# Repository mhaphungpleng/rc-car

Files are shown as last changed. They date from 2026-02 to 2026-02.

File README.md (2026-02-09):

# RC-Car ROS2 Control System

โปรเจกต์นี้เป็นระบบควบคุมรถ RC ที่พัฒนาด้วย **ROS2**  
รองรับทั้งโหมดควบคุมแบบ **Manual (Joystick)** และ **Autonomous (PID Controller)**  
ระบบถูกออกแบบแบบ **Modular** เพื่อแยก perception, control และ hardware interface

---

## Project Structure

rc-car/
 /firmware/ # โค้ดไมโครคอนโทรลเลอร์ / ESC / Servo
 /software/ # ROS2 nodes สำหรับ manual และ autonomous control
 /models/ # สมการควบคุมและแบบจำลองทางคณิตศาสตร์
 /images/ # block diagram และ hardware setup
 /docs/ # รายงานและเอกสาร
 /launch/ # ROS2 launch files

---

## System Overview

ระบบควบคุมประกอบด้วย

- Sensor input (เช่น LiDAR)
- PID Controller สำหรับ steering และ throttle
- Manual joystick control
- ESC และ Servo สำหรับควบคุมรถ

ระบบสามารถทำงานได้ 2 โหมด

**Manual mode**

**Autonomous mode**

---

## Manual Control

Node `joy_to_manual`

Subscribe:
- `/joy`

Publish:
- `/cmd_esc_manual`
- `/cmd_s1_manual`

---

## Autonomous Control

ระบบใช้ค่า error จาก target  
คำนวณ steering และ throttle ด้วย **PID Controller**

---

## Hardware

- RC Car Platform
- ESC Motor Controller
- Steering Servo
- LiDAR Sensor
- ROS2 Computer / Embedded Controller
- Joystick Controller

Hardware diagram:

---

## Diagrams

- Block Diagram: `images/block_diagram.png`
- PID Control Diagram: `images/PID.png`
- Hardware Setup: `images/hardware_setup.png`

---

## Features

- Modular ROS2 architecture
- PID control สำหรับ steering และ throttle
- รองรับ manual override
- Smooth ESC ramp control
- สามารถต่อยอด perception และ navigation ได้

---

## Future Work

- Autonomous navigation เต็มรูปแบบ
- Obstacle avoidance
- Sensor fusion (LiDAR + Camera)
- Adaptive PID tuning

---

โปรเจกต์นี้จัดทำขึ้นเพื่อการศึกษาและพัฒนาในสาย **Robotics และ Control System**

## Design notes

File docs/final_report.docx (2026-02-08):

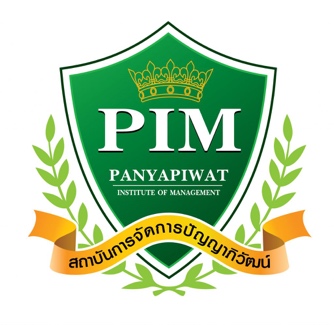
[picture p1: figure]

การทำหุ่นยนต์อัตโนมัติ

(Autonomous Robotics Project)

จัดทำโดย

นาย ภาณุภร มาศรี

นาย นฤเบศ หนูเจริญ

นาย ฟุรกอน สาแม

สาขาวิชาหุ่นยนต์และระบบอัตโนมัติ

คณะวิศวกรรมศาสตร์และเทคโนโลยี

สถาบันการจัดการปัญญาภิวัฒน์

บทคัดย่อ

หัวข้อโครงงาน: การทำหุ่นยนต์อัตโนมัติ คณะ: วิศวกรรมศาสตร์และเทคโนโลยี สาขาหุ่นยนต์และระบบอัตโนมัติ ผู้จัดทำ:นาย ภาณุภร มาศรี, นาย นฤเบศ หนูเจริญ, นาย ฟุรกอน สาแม

โครงงานนี้มีวัตถุประสงค์เพื่อศึกษาและพัฒนาหุ่นยนต์อัตโนมัติที่สามารถปฏิบัติภารกิจ [ใส่หน้าที่หลัก เช่น การเคลื่อนที่หลบหลีกสิ่งกีดขวาง / การเดินตามเส้น / การขนส่งวัสดุ] โดยเน้นการบูรณาการองค์ความรู้ด้านวิศวกรรมหุ่นยนต์ ทั้งในส่วนของการออกแบบโครงสร้างทางกล (Mechanical Design) การออกแบบวงจรระบบควบคุม (Electronic Circuit) และการพัฒนาซอฟต์แวร์ควบคุม (Firmware Development)

ในการพัฒนาหุ่นยนต์ครั้งนี้ ได้เลือกใช้ [ระบุบอร์ดควบคุม เช่น ไมโครคอนโทรลเลอร์ ESP32 / Arduino] เป็นหน่วยประมวลผลหลัก ทำงานร่วมกับเซนเซอร์ [ระบุชื่อเซนเซอร์ เช่น อัลตราโซนิก / อินฟราเรด] เพื่อรับข้อมูลสภาพแวดล้อม และขับเคลื่อนด้วย [เช่น Butlet Motor ผ่านโมดูลขับมอเตอร์ การเขียนโปรแกรมควบคุมใช้อัลกอริทึม PID Control เพื่อให้หุ่นยนต์สามารถตัดสินใจและตอบสนองต่อเงื่อนไขต่างๆ ได้อย่างแม่นยำ

จากการทดสอบประสิทธิภาพการทำงานของหุ่นยนต์ในสภาพแวดล้อมจำลอง พบว่าหุ่นยนต์สามารถ [ระบุผลการทดลอง เช่น เคลื่อนที่ไปยังจุดหมายได้อย่างถูกต้อง / ตรวจจับสิ่งของได้ในระยะ 1.5 เมตรโดยมีอัตราความสำเร็จในการปฏิบัติงานเฉลี่ยร้อยละ 90% อย่างไรก็ตาม ยังมีข้อจำกัดในเรื่อง ที่ตัวหุ่นยนต์ไม่สามารถล็อก target ได้ตามที่ต้องการสามารถมี่สิ่งของอื่นมารบกวนการตรวจจับของเซนเซอร์ได้ซึ่งสามารถนำไปพัฒนาต่อยอดในเชิงอุตสาหกรรมหรือการใช้งานที่ซับซ้อนขึ้นในอนาคต

สารบัญ (Table of Contents)

บทคัดย่อ ......................................................................................................................... ก

สารบัญเนื้อหา.................................................................................................................... ข

บทที่ 1 บทนำ....................................................................................................................1

- 1.1 ที่มาและความสำคัญของโครงงาน ................................................................................................................ 1
- 1.2 วัตถุประสงค์ของโครงงาน ........................................................................................................................... 2
- 1.3 ขอบเขตการดำเนินงาน ................................................................................................................................. 2
- 1.4 ผู้ใช้งานของโครงงาน ................................................................................................................................... 3
- 1.5 ประโยชน์ที่คาดว่าจะได้รับ ........................................................................................................................... 3

บทที่ 2 ฐานข้อมูลและการประยุกต์ใช้ระบบควบคุม ......................................................................... 4

- 2.1 ฐานข้อมูลการทดสอบรถอัตโนมัติ ................................................................................................................ 4
- 2.2 ฐานข้อมูลเซนเซอร์ ....................................................................................................................................... 4
- 2.3 การประยุกต์ใช้ Machine Learning และระบบควบคุม .................................................................. 5
  - 2.3.1 การควบคุมความเร็วด้วยสมการ PID ......................................................... 5
  - 2.3.2 การควบคุมทิศทางด้วย Gyroscope และเซอร์โวมอเตอร์ ................................................. 5
- 2.4 ฐานข้อมูลในการตัดสินใจเลือกอุปกรณ์ (เอกสารอ้างอิงชุดอุปกรณ์) ............................................................ 6

บทที่ 3 วิธีดำเนินงาน ....................................................................................................... 7

- 3.1 เครื่องมือที่ใช้ (Hardware) ............................................................................. 7
- 3.2 ซอฟต์แวร์ที่ใช้ในการพัฒนา (Software)................................................................ 8
  - 3.2.1 ระบบปฏิบัติการ Ubuntu และ ROS 2 .................................................. 8
  - 3.2.2 Arduino IDE และการออกแบบทางวิศวกรรม (SolidWorks / Fusion 360) .. .......................................................................................................... 9
- 3.3 ขั้นตอนการดำเนินงาน ................................................................................................................................. 10
  - 3.3.1 การออกแบบและประกอบโครงสร้างรถต้นแบบ .................................................................... 10
  - 3.3.2 การพัฒนาโปรแกรมควบคุมและปัญหาการรับส่งข้อมูล ......................................................... 11
  - 3.3.3 การจัดการสัญญาณรบกวนด้วย Alpha Filter .......................................... 12
  - 3.3.4 การประยุกต์ใช้ Lidar และการจัดการ Node ใน ROS 2 ............................ 13
  - 3.3.5 แนวคิดการออกแบบระบบแซงอัตโนมัติ ................................................................................. 14

บทที่ 4 การพัฒนาและการทำงานของระบบซอฟต์แวร์ ................................................................... 15

- 4.1 ภาพรวมสถาปัตยกรรมซอฟต์แวร์ ................................................................................................................ 15
- 4.2 ระบบควบคุมพวงมาลัยอัตโนมัติจาก LiDAR (PD Controller) ............................... 16
- 4.3 ระบบควบคุมรถด้วยคีย์บอร์ด (Manual Control) ................................................. 17
- 4.4 ระบบกราฟิกยูสเซอร์อินเทอร์เฟซ (GUI) ............................................................... 18
- 4.5 การจัดการโค้ดและโครงสร้างโปรแกรม ...................................................................................................... 19
- 4.6 สรุปการทำงานของระบบ ..............................................................................................................................19

บทที่ 5 สรุปผลการดำเนินงานและข้อเสนอแนะ ........................................................................... 20

- 5.1 สรุปผลการดำเนินงาน ................................................................................................................................... 20
- 5.2 ปัญหาและอุปสรรคที่พบ ............................................................................................................................... 21
- 5.3 ข้อเสนอแนะและแนวทางการพัฒนาต่อยอด ................................................................................................. 21

บทที่ 1

บทนำ

### ที่มาและความสำคัญของโครงงาน

กลุ่มผู้จัดทำได้เลือกพัฒนารถต้นแบบขึ้นมาใหม่ทั้งคัน ตั้งแต่การออกแบบโครงสร้างและบอดี้ของรถ ไปจนถึงการพัฒนาระบบการทำงานต่าง ๆ ของตัวรถ เนื่องจากเล็งเห็นว่าการดำเนินโครงงานในลักษณะนี้สามารถช่วยพัฒนาความรู้และทักษะของผู้จัดทำได้ในหลากหลายด้าน การสร้างรถหนึ่งคันจำเป็นต้องอาศัยกระบวนการทำงานหลายส่วน ไม่ว่าจะเป็นการออกแบบตัวรถ ซึ่งไม่ได้เป็นเพียงการออกแบบในเชิงรูปลักษณ์เท่านั้น แต่ยังต้องมีการคำนวณและวิเคราะห์ในแต่ละจุด เพื่อให้รถสามารถเคลื่อนที่ได้อย่างมีประสิทธิภาพ มีความเสถียร และสามารถทำความเร็วได้ตามที่ต้องการ

นอกจากนี้ โครงงานยังประกอบด้วยการพัฒนาระบบควบคุม การเขียนโปรแกรม รวมถึงการออกแบบและต่อวงจรไฟฟ้าให้สามารถทำงานร่วมกันได้อย่างเหมาะสม กระบวนการเหล่านี้ช่วยเสริมสร้างความเข้าใจด้านวิศวกรรม การแก้ไขปัญหาเชิงระบบ และการทำงานเป็นทีม ส่งผลให้ผู้จัดทำสามารถพัฒนาศักยภาพและทักษะทางเทคนิคได้อย่างรอบด้าน

### วัตถุประสงค์ของโครงงาน

1. เพื่อศึกษาการประยุกต์ใช้เทคโนโลยีเซนเซอร์และระบบควบคุมอัตโนมัติในงานยานยนต์อัจฉริยะ
2. เพื่อออกแบบและพัฒนารถต้นแบบที่สามารถเคลื่อนที่ได้ด้วยตนเอง
3. เพื่อพัฒนาระบบควบคุมการเคลื่อนที่ของรถให้สามารถติดตามรถคันข้างหน้าโดยอัตโนมัติ
4. เพื่อออกแบบระบบตรวจจับสภาพแวดล้อมรอบตัวรถ เช่น ระยะห่างและตำแหน่งของรถคันอื่น
5. เพื่อพัฒนาระบบตัดสินใจในการแซงรถคันข้างหน้าอย่างอัตโนมัติภายใต้เงื่อนไขที่กำหนด

### ขอบเขตการดำเนินงาน

ในขั้นตอนแรก กลุ่มผู้จัดทำได้ดำเนินการออกแบบโครงสร้างและบอดี้ของรถ โดยใช้โปรแกรม Fusion 360 เพื่อออกแบบและจำลองการทำงานของตัวรถในลักษณะสามมิติ เพื่อประเมินความเหมาะสมของโครงสร้างและความเป็นไปได้ในการใช้งานจริง

ควบคู่ไปกับการออกแบบเชิงกล กลุ่มผู้จัดทำได้พัฒนาชุดคำสั่งพื้นฐานสำหรับควบคุมการทำงานของระบบ โดยอาศัยหลักการเขียนโปรแกรมพื้นฐาน เช่น การกำหนดตัวแปร การใช้คำสั่งเงื่อนไข การวนซ้ำ และการแบ่งโปรแกรมออกเป็นฟังก์ชัน ซึ่งถือเป็นพื้นฐานสำคัญในการพัฒนาระบบควบคุมรถอัตโนมัติให้สามารถทำงานได้อย่างถูกต้องและมีประสิทธิภาพ

### ผู้ใช้งานของโครงงาน

ผู้ใช้งานของโครงงานนี้ ได้แก่ ผู้จัดทำและผู้ที่เกี่ยวข้องกับการทดสอบระบบ โดยมีวัตถุประสงค์เพื่อใช้ในการศึกษา ทดลอง และพัฒนาทางเทคโนโลยี

### ประโยชน์ที่คาดว่าจะได้รับ

ชิ้นงานของกลุ่มผู้จัดทำมีศักยภาพในการเป็นแนวทางหรือแรงบันดาลใจให้แก่ผู้ที่สนใจในการพัฒนาโครงงานด้านยานยนต์อัตโนมัติ ซึ่งสามารถนำไปต่อยอดในการสร้างหรือพัฒนาชิ้นงานในลักษณะเดียวกันได้

สำหรับกลุ่มผู้จัดทำ โครงงานนี้ช่วยเสริมสร้างความรู้ ความสามารถ และทักษะในหลายด้าน ไม่ว่าจะเป็นด้านการวางแผน การออกแบบ การพัฒนาระบบ การแก้ไขปัญหา และการทำงานเป็นทีม อีกทั้งยังสามารถนำองค์ความรู้และประสบการณ์ที่ได้รับไปประยุกต์ใช้กับงานหรือโครงการอื่น ๆ ในอนาคตได้

บทที่ 2

### ฐานข้อมูลการทดสอบรถอัตโนมัติ

ใช้สำหรับจัดเก็บข้อมูลที่ได้จากการทดสอบระบบรถอัตโนมัติในแต่ละครั้ง เพื่อใช้ในการวิเคราะห์ประสิทธิภาพของระบบ

ข้อมูลที่จัดเก็บประกอบด้วย

- วันที่และเวลาที่ทำการทดสอบ
- ความเร็วของรถ
- ระยะห่างจากรถคันหน้า
- สถานะการแซง (แซง / ไม่แซง)
- ผลการทำงานของระบบ (สำเร็จ / ล้มเหลว)

ข้อมูลดังกล่าวถูกนำมาใช้ในการเปรียบเทียบผลการทดสอบในแต่ละครั้ง เพื่อประเมินประสิทธิภาพและความเสถียรของระบบ

### ฐานข้อมูลเซนเซอร์

ใช้สำหรับจัดเก็บค่าที่อ่านได้จากเซนเซอร์ต่าง ๆ แบบต่อเนื่อง เพื่อใช้ในการประมวลผลและวิเคราะห์การทำงานของระบบ

ข้อมูลที่จัดเก็บประกอบด้วย

- ค่าที่อ่านจาก Ultrasonic / Camera
- ระยะห่าง (เซนติเมตร)
- เวลาที่อ่านค่า

### การประยุกต์ใช้ Machine Learning และระบบควบคุม

ในการควบคุมให้หุ่นยนต์สามารถตัดสินใจได้ว่าจะต้องชะลอความเร็ว เร่งความเร็ว แซง หรือเลี้ยว กลุ่มผู้จัดทำได้ออกแบบระบบควบคุมโดยอาศัยข้อมูลจากเซนเซอร์ต่าง ๆ ที่ติดตั้งบนหุ่นยนต์

สำหรับการควบคุมความเร็ว หุ่นยนต์จะใช้เซนเซอร์วัดระยะทางเพื่อตรวจจับระยะห่างจากวัตถุหรือรถคันหน้า ข้อมูลที่ได้จะถูกนำไปประมวลผลด้วยสมการควบคุมแบบ PID (Proportional–Integral–Derivative) เพื่อคำนวณค่าที่เหมาะสมในการเร่งหรือชะลอความเร็วของมอเตอร์ ทำให้หุ่นยนต์สามารถปรับความเร็วได้อย่างเหมาะสมและมีความเสถียร

ในส่วนของการควบคุมทิศทางการเคลื่อนที่ หุ่นยนต์ใช้เซนเซอร์ไจโรสโคป (Gyroscope) ในการตรวจจับมุมการเอียงหรือมุมการหมุนของตัวรถ เมื่อระบบตรวจพบว่ารถเบี่ยงออกจากแนวที่กำหนด ข้อมูลดังกล่าวจะถูกนำไปสั่งงานเซอร์โวมอเตอร์ให้ปรับมุมในทิศทางตรงกันข้าม

ตัวอย่างเช่น หากตรวจพบการเอียงจำนวน 3 องศา ระบบจะสั่งให้เซอร์โวมอเตอร์ปรับมุม 3 องศาในทิศทางตรงกันข้าม เพื่อแก้ไขทิศทางให้รถกลับมาเคลื่อนที่ในแนวที่ถูกต้อง ส่งผลให้การเคลื่อนที่มีความแม่นยำและปลอดภัยมากยิ่งขึ้น

ฐานข้อมูลในการตัดสินใจเลือกอุปกรณ์

Espressif Systems. (n.d.). *ESP32 – Wikipedia*. Retrieved January 2026, from https://en.wikipedia.org/wiki/ESP32

MG996R Servo Motor Specifications, ETT Co., Ltd. (n.d.). Retrieved January 2026, from https://www.etteam.com

Arduino4Pro. (n.d.). *LiPo battery category*. Retrieved January 2026, from https://www.arduino4pro.com/category/152/power-supply-regulator/lipo-litium-battery-charger

Hobbywing. (n.d.). *Skywalker ESC specifications*. Retrieved January 2026, from https://www.hobbywing.com/en/uploads/file/95b6d53e5e0c47b04f0054db6e894e31.pdf

Web Electronics Parts Category. (n.d.). *DC-DC step down regulators*. Retrieved January 2026, from https://www.as99shop.com/category/switching-powersupply/step-down-regulator

YDLIDAR X3 Pro Lidar. (n.d.). Retrieved January 2026, from https://www.arduitronics.com/product/5678/ydlidar-x3-pro-lidar-360-degree-laser-range-scanner-8m-support-ros1-ros2

Raspberry Pi Foundation. (n.d.). *Raspberry Pi 5 documentation*. Retrieved January 2026, from https://www.raspberrypi.com/products/raspberry-pi-5/

บทที่ 3

## วิธีดำเนินงาน

### เครื่องมือที่ใช้

#### Hardware

- โช้คไฮดรอลิกโลหะ ใช้เพื่อช่วยเพิ่มเสถียรภาพของรถขณะเคลื่อนที่และรองรับการทำความเร็ว
- ESP32 Mini ทำหน้าที่รับข้อมูลจากเซนเซอร์ต่าง ๆ ประมวลผล และควบคุมการทำงานของมอเตอร์ตามโปรแกรมที่เขียนไว้
- Servo Motor ทำหน้าที่ควบคุมการเลี้ยวของรถ เนื่องจากสามารถปรับมุมได้อย่างแม่นยำ
- เกลียวทองเหลือง ใช้สำหรับยึดน็อตและชิ้นส่วนต่าง ๆ
- เพลาสแตนเลส ทำหน้าที่ส่งแรงหมุนจากมอเตอร์ไปยังล้อ
- ตลับลูกปืน
- ล้อรถ
- แบตเตอรี่ LiPo 2S 7.4V 2200 mAh ทำหน้าที่เป็นแหล่งจ่ายพลังงานหลักให้กับระบบทั้งหมดของรถต้นแบบ
- สกรู
- บัลเลตมอเตอร์ ทำหน้าที่เป็นแหล่งกำลังขับเคลื่อนหลักของรถ
- Skywalker ไดรฟ์มอเตอร์ (ESC) ใช้ควบคุมการหมุนและความเร็วของมอเตอร์ รวมถึงรองรับการเบรก
- ToF Sensor ใช้เป็นเซนเซอร์วัดระยะทาง
- DC-DC Converter 5V 5A ใช้ลดแรงดันไฟจากแบตเตอรี่ให้อยู่ในระดับที่อุปกรณ์สามารถใช้งานได้
- Connector ใช้สำหรับเชื่อมต่ออุปกรณ์ เพื่อความสะดวกในการถอดประกอบ

Software:

### Ubuntu (Operating System) ใช้เป็นระบบปฏิบัติการหลักสำหรับการพัฒนาและควบคุมระบบหุ่นยนต์ รวมถึงการติดตั้ง ROS2 และการประมวลผลข้อมูลจากเซนเซอร์ Ubuntu เป็นระบบปฏิบัติการแบบโอเพนซอร์สที่ใช้เป็นแพลตฟอร์มหลักในการพัฒนาและควบคุมระบบของหุ่นยนต์ โดยรองรับการทำงานของ ROS2 และการประมวลผลข้อมูลจากเซนเซอร์ต่าง ๆ

### ROS 2 (Robot Operating System 2)

- จัดการการสื่อสารระหว่าง NODE
- ประมวลผลข้อมูลจาก LiDAR
- ควบคุมการตัดสินใจ เช่น การตามรถและการแซง

### ROS 2 เป็นเฟรมเวิร์กสำหรับพัฒนาระบบหุ่นยนต์ ทำหน้าที่จัดการการสื่อสารและประมวลผลข้อมูลระหว่างอุปกรณ์และซอฟต์แวร์ต่าง ๆ ภายในระบบ ทำให้สามารถควบคุมการเคลื่อนที่และการตัดสินใจของหุ่นยนต์ได้อย่างมีประสิทธิภาพ

### Arduino IDE ใช้สำหรับเขียนและอัปโหลดโปรแกรมไปยัง ESP32 เพื่อควบคุมอุปกรณ์ฮาร์ดแวร์ เช่น มอเตอร์ เซอร์โว และ ESC Arduino IDE ใช้สำหรับพัฒนาและอัปโหลดโปรแกรมควบคุมไปยังไมโครคอนโทรลเลอร์ ESP32 เพื่อควบคุมการทำงานของอุปกรณ์ต่าง ๆ ภายในระบบ เช่น มอเตอร์และเซอร์โวมอเตอร์

### SolidWorks

ใช้สำหรับออกแบบชิ้นส่วนทางกลและโครงสร้างของรถ เช่น บอดี้รถ ฐานยึดอุปกรณ์ และโครงสร้างตัวถัง SolidWorks เป็นโปรแกรมออกแบบทางวิศวกรรมสามมิติ ใช้สำหรับออกแบบโครงสร้างและชิ้นส่วนทางกลของรถต้นแบบ เพื่อให้สามารถวางอุปกรณ์และประกอบระบบได้อย่างเหมาะสม

### Fusion 360 (Fusion3D) ใช้ในการออกแบบชิ้นส่วน 3 มิติและปรับแก้โมเดลก่อนนำไปผลิตจริง เช่น การพิมพ์ 3 มิติ Fusion 360 ใช้สำหรับออกแบบและปรับแก้ชิ้นส่วนสามมิติ รวมถึงเตรียมโมเดลสำหรับการผลิต เช่น การพิมพ์สามมิติ เพื่อให้ชิ้นส่วนสามารถใช้งานได้จริงกับรถต้นแบบ

## ขั้นตอนการดำเนินงาน

ในขั้นเริ่มต้น ภายหลังจากได้รับโจทย์จากอาจารย์ผู้สอน กลุ่มผู้จัดทำได้พิจารณาถึงลักษณะของรถต้นแบบที่ต้องนำมาใช้งานร่วมกัน โดยเนื่องจากรถของอาจารย์มีความเร็วค่อนข้างสูง และโครงงานที่พัฒนาขึ้นเป็นรถระบบอัตโนมัติที่ต้องสามารถติดตามรถคันหน้าได้อย่างต่อเนื่อง หากรถมีความเร็วไม่เพียงพออาจทำให้ระบบติดตามล้มเหลวหรือหลุดจากการควบคุม กลุ่มผู้จัดทำจึงมีแนวคิดในการเลือกใช้มอเตอร์ที่สามารถให้ความเร็วและกำลังขับสูง

อย่างไรก็ตาม จากการศึกษาและทดลองพบว่ามอเตอร์ที่มีกำลังขับสูงส่วนใหญ่มักมีข้อจำกัดด้านการเบรก เนื่องจากแรงขับที่มาก ส่งผลให้ไม่สามารถควบคุมการหยุดหรือชะลอความเร็วได้อย่างมีประสิทธิภาพ ซึ่งถือเป็นปัญหาแรกที่พบ นอกจากนี้ ระหว่างกระบวนการประกอบรถต้นแบบยังพบปัญหาย่อยอื่น ๆ เช่น อุปกรณ์บางชนิดไม่สามารถใช้งานได้ตามที่คาดหวัง และโครงสร้างบอดี้ของรถที่ประกอบแล้วเกิดความไม่พอดีกันในบางตำแหน่ง

ต่อมา กลุ่มผู้จัดทำได้เริ่มดำเนินการออกแบบตัวรถ โดยเริ่มจากการออกแบบบอดี้ของรถให้สามารถเคลื่อนที่ได้ด้วยความเร็วสูง พร้อมทั้งยังต้องรองรับการเลี้ยวได้อย่างมีประสิทธิภาพ ควบคู่ไปกับการออกแบบวงจรไฟฟ้าที่ใช้ในระบบของรถต้นแบบ เมื่อได้รูปแบบการออกแบบที่เหมาะสมแล้ว จึงดำเนินการประกอบตัวรถและจัดวางตำแหน่งอุปกรณ์ต่าง ๆ เพื่อประเมินลักษณะการทำงานโดยรวมของรถในเบื้องต้น

หลังจากนั้น กลุ่มผู้จัดทำได้เริ่มพัฒนาโปรแกรมควบคุมการทำงานของรถ โดยเริ่มจากการเขียนโค้ดพื้นฐาน (Basic Code) เพื่อทดสอบการรับและส่งค่าของอุปกรณ์ไฟฟ้าต่าง ๆ ผ่านไมโครคอนโทรลเลอร์ ESP32 C3 จากการทดลองอัปโหลด Micro-ROS พบว่าไม่สามารถรันโปรแกรมได้ เนื่องจากข้อจำกัดด้านสมรรถนะการประมวลผลของตัวไมโครคอนโทรลเลอร์

ต่อมาได้ทดลองใช้งานเซนเซอร์ Gyroscope รุ่น 5883L แต่ไม่สามารถดึงค่ามุม Yaw ออกมาใช้งานได้ จากนั้นจึงเริ่มพัฒนาและเขียนโปรแกรม Micro-ROS อย่างจริงจัง ซึ่งในขั้นตอนนี้พบปัญหาตั้งแต่ระยะเริ่มต้น กล่าวคือ หลังจากอัปโหลดโค้ดทั้งหมดแล้ว ระบบสามารถรับและส่งข้อมูลได้เพียงประมาณ 1 Hz ทำให้การตอบสนองของระบบล่าช้าเกินไป

กลุ่มผู้จัดทำจึงทำการตรวจสอบสาเหตุและพบว่าอุปกรณ์ที่ใช้งานร่วมกับ Raspberry Pi จำเป็นต้องใช้บอร์ดเวอร์ชัน 2.0.2 หลังจากติดตั้งเวอร์ชันดังกล่าวแล้ว พบปัญหาใหม่คือ Arduino IDE ไม่สามารถคอมไพล์โปรแกรมได้ เนื่องจากไม่สามารถค้นหาไฟล์ Python ที่เกี่ยวข้องได้ กลุ่มผู้จัดทำจึงแก้ไขปัญหาโดยการรันโปรแกรมผ่านไฟล์ environment ของ Python จนสามารถคอมไพล์ได้สำเร็จ

เมื่อทำการทดสอบระบบอีกครั้ง พบว่าความเร็วในการรับส่งข้อมูลเพิ่มขึ้น แต่ค่าที่ได้จากเซนเซอร์ยังมีความไม่เสถียร กลุ่มผู้จัดทำจึงปรับหน่วงค่าของเซนเซอร์เพื่อให้ข้อมูลมีความเหมาะสมมากขึ้น อย่างไรก็ตาม เมื่อเริ่มนำค่าที่ได้ไปควบคุมเซอร์โวมอเตอร์ พบว่าเซอร์โวเกิดอาการส่ายอย่างรุนแรง จึงแก้ไขปัญหาโดยการเพิ่ม Alpha Filter เพื่อทำให้ค่าที่ได้มีความนิ่งมากขึ้น แม้ว่าจะทำให้การตอบสนองช้าลงบ้าง แต่ช่วยเพิ่มความเสถียรให้กับระบบโดยรวม

ในขั้นตอนถัดมา กลุ่มผู้จัดทำได้ทดลองใช้งานเซนเซอร์ที่เคยใช้งานก่อนหน้านี้ แต่พบว่าไม่สามารถตรวจจับวัตถุได้ในระยะที่ต้องการ จึงตัดสินใจเปลี่ยนมาใช้เซนเซอร์ Lidar จากการทดลองใช้งาน พบปัญหาในขั้นแรกคือไม่สามารถสั่งให้ Lidar ทำการสแกนผ่านระบบ ROS2 ได้ เนื่องจากโค้ดที่ผู้ผลิตให้มาไม่สามารถรันได้ กลุ่มผู้จัดทำจึงทำการแก้ไขโค้ดต้นฉบับของ Lidar จนสามารถสั่งงานให้ทำการสแกนผ่าน ROS2 ได้สำเร็จ

เมื่อทดสอบการทำงานของ Lidar ร่วมกับอุปกรณ์อื่น ๆ เช่น Gyroscope พบปัญหาเพิ่มเติม กล่าวคือ เมื่อมีการสั่งงานอุปกรณ์หลายชนิดพร้อมกัน ข้อมูลที่ส่งมาจาก Lidar และ Gyroscope ในเวลาใกล้เคียงกัน ส่งผลให้เซอร์โวมอเตอร์เกิดอาการส่ายอย่างรุนแรงอีกครั้ง กลุ่มผู้จัดทำจึงแก้ไขปัญหาโดยการออกแบบและเขียน Node ใหม่ในระบบ ROS2 ให้รวมการประมวลผลข้อมูลจากเซนเซอร์หลายตัวไว้ใน Node เดียวกัน เพื่อให้การส่งข้อมูลเป็นไปในลักษณะรวมศูนย์ ส่งผลให้ค่าที่ใช้ควบคุมมีความเสถียรมากขึ้นและลดอาการส่ายของเซอร์โวมอเตอร์ได้อย่างมีประสิทธิภาพ

ภายหลังจากที่กลุ่มผู้จัดทำสามารถแก้ไขปัญหาในขั้นตอนดังกล่าวและทำให้ระบบควบคุมการเคลื่อนที่ของรถมีความเสถียรแล้ว ขั้นตอนถัดมาคือการพัฒนาระบบให้รถสามารถทำการแซงได้โดยอัตโนมัติ เมื่อมีสิ่งกีดขวางหรือรถคันอื่นอยู่ด้านหน้ารถต้นแบบ

กลุ่มผู้จัดทำได้ออกแบบแนวคิดการแซงอัตโนมัติโดยอาศัยการกำหนดเงื่อนไขภายในโปรแกรมควบคุม เมื่อระบบตรวจจับได้ว่ารถเข้าใกล้วัตถุด้านหน้าในระยะที่กำหนดไว้ในโค้ด รถจะทำการเปลี่ยนโหมดการทำงานจากโหมดติดตามเป็นโหมดแซงอัตโนมัติ และดำเนินการตามค่าที่ได้ตั้งค่าไว้ล่วงหน้า

ตัวอย่างเช่น เมื่อเซนเซอร์ตรวจพบสิ่งกีดขวางอยู่ในระยะที่กำหนด ระบบจะสั่งให้รถเลี้ยวไปทางด้านขวา พร้อมทั้งเร่งความเร็วเพื่อทำการแซง โดยจะคงการเร่งความเร็วไว้เป็นระยะเวลาประมาณ 2 วินาที หลังจากนั้นระบบจะสั่งให้รถกลับเข้าสู่ทิศทางเดิม และปรับการเคลื่อนที่ให้วิ่งตรงไปข้างหน้าอย่างต่อเนื่อง โดยไม่มีการติดตามรถคันหน้าอีกต่อไปในช่วงเวลาดังกล่าว

ในขั้นตอนสุดท้าย กลุ่มผู้จัดทำได้พัฒนาและเพิ่มระบบส่วนติดต่อผู้ใช้งาน (Graphical User Interface: GUI) เพื่ออำนวยความสะดวกในการควบคุมรถต้นแบบผ่านหน้าจอ ผู้ใช้งานสามารถปรับค่าพารามิเตอร์ต่าง ๆ ของระบบได้ตามต้องการ รวมถึงสามารถเลือกโหมดการทำงานของรถได้ทั้งในโหมดควบคุมด้วยตนเอง (Manual Mode) และโหมดอัตโนมัติ (Auto Mode)

จากการดำเนินงานทั้งหมด ส่งผลให้รถต้นแบบสามารถทำงานได้ตามวัตถุประสงค์ที่กำหนดไว้ และยังสามารถนำระบบที่พัฒนาขึ้นไปปรับปรุง แก้ไข หรือพัฒนาต่อยอดเพิ่มเติมในอนาคตได้ตามความเหมาะสม

บทที่ 4

การพัฒนาและการทำงานของระบบซอฟต์แวร์

## 4.1 ภาพรวมสถาปัตยกรรมซอฟต์แวร์

ระบบซอฟต์แวร์ของโครงงานนี้พัฒนาบนระบบปฏิบัติการ Ubuntu และใช้ ROS 2 (Robot Operating System 2) เป็นแกนกลางในการสื่อสารระหว่างโหนด (Node) ต่าง ๆ ภายในระบบ โดยมีการแบ่งหน้าที่การทำงานออกเป็นหลายส่วนเพื่อความเป็นระเบียบและง่ายต่อการพัฒนาในอนาคต

ซอฟต์แวร์ทั้งหมดสามารถแบ่งออกเป็น 3 ส่วนหลัก ได้แก่

1. ระบบควบคุมพวงมาลัยอัตโนมัติจากข้อมูล LiDAR
2. ระบบควบคุมรถด้วยคีย์บอร์ด (Manual Control)
3. ระบบควบคุมและแสดงผลผ่านกราฟิกยูสเซอร์อินเทอร์เฟซ (GUI)

การสื่อสารระหว่างโมดูลต่าง ๆ ถูกดำเนินการผ่าน ROS 2 Topic และ Action เพื่อให้ระบบสามารถทำงานร่วมกันได้แบบเรียลไทม์

## 4.2 ระบบควบคุมพวงมาลัยอัตโนมัติจาก LiDAR

ระบบควบคุมพวงมาลัยอัตโนมัติถูกพัฒนาด้วยภาษา Python บน ROS 2 โดยทำหน้าที่รับข้อมูลมุมเบี่ยงเบนของเป้าหมายจากเซนเซอร์ LiDAR และนำมาคำนวณเพื่อควบคุมมุมเลี้ยวของเซอร์โวมอเตอร์

หลักการควบคุมที่ใช้คือ ตัวควบคุมแบบ PD (Proportional–Derivative Controller) ซึ่งช่วยให้รถสามารถปรับทิศทางได้อย่างแม่นยำและลดการสั่นของพวงมาลัย

โค้ดการคำนวณ PD Controller จากข้อมูล LiDAR

จากโค้ดข้างต้น ค่า Error ที่ได้จากมุมเบี่ยงเบนของเป้าหมายจะถูกนำมาคำนวณผ่านพจน์ Proportional และ Derivative จากนั้นจึงนำผลลัพธ์ไปปรับมุมพวงมาลัยของรถให้เบี่ยงเบนไปตามทิศทางของเป้าหมายที่ตรวจพบ

นอกจากนี้ ระบบยังมีโหมด Yaw Hold เพื่อช่วยรักษาทิศทางของรถให้วิ่งตรงในกรณีที่ไม่พบเป้าหมายจาก LiDAR

เพื่อเพิ่มความปลอดภัย ระบบถูกออกแบบให้รองรับโหมด Emergency Stop ซึ่งจะสั่งให้พวงมาลัยกลับสู่ตำแหน่งกึ่งกลางและหยุดมอเตอร์ทันทีเมื่อเกิดสถานการณ์ฉุกเฉิน รวมถึงมีฟังก์ชัน Soft Reset สำหรับรีเซตค่าการควบคุมโดยไม่ต้องเริ่มระบบใหม่ทั้งหมด

## 4.3 ระบบควบคุมรถด้วยคีย์บอร์ด (Manual Control)

ระบบควบคุมด้วยคีย์บอร์ดถูกพัฒนาขึ้นเพื่อใช้ในการทดสอบและควบคุมรถด้วยมนุษย์ โดยผู้ใช้สามารถควบคุมความเร็วของมอเตอร์และมุมเลี้ยวของเซอร์โวมอเตอร์ผ่านการกดปุ่มบนแป้นพิมพ์

โค้ดการรับคำสั่งจากแป้นพิมพ์

คำสั่งที่ผู้ใช้ป้อนจะถูกแปลงเป็นข้อมูลในรูปแบบ JSON และส่งผ่าน ROS 2 Topic ไปยังไมโครคอนโทรลเลอร์ เพื่อสั่งงานมอเตอร์และเซอร์โวมอเตอร์โดยตรง ระบบนี้ช่วยให้สามารถตรวจสอบการทำงานของฮาร์ดแวร์และระบบขับเคลื่อนได้อย่างสะดวกในระหว่างการพัฒนา

## 4.4 ระบบกราฟิกยูสเซอร์อินเทอร์เฟซ (GUI)

ระบบ GUI ถูกพัฒนาด้วยไลบรารี Tkinter ร่วมกับ ROS 2 โดยมีวัตถุประสงค์เพื่อเพิ่มความสะดวกในการควบคุมและตรวจสอบสถานะของรถต้นแบบ ผู้ใช้สามารถปรับตำแหน่งเซอร์โวมอเตอร์ผ่านแถบเลื่อน (Slider) และเลือกโหมดการทำงานของระบบได้

โค้ดการส่งคำสั่งจาก GUI

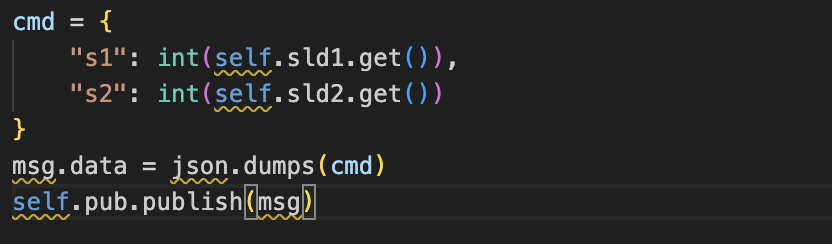
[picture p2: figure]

นอกจากนี้ GUI ยังสามารถแสดงข้อมูล Telemetry ที่ได้รับจากไมโครคอนโทรลเลอร์ เช่น ค่ามุม Yaw และตำแหน่งปัจจุบันของเซอร์โวมอเตอร์ ซึ่งช่วยให้ผู้ใช้งานสามารถติดตามสถานะของระบบได้แบบเรียลไทม์

## 4.5 การจัดการโค้ดและโครงสร้างโปรแกรม

โค้ดทั้งหมดของโครงงานถูกพัฒนาในรูปแบบแยกเป็นโมดูลตามหน้าที่การทำงาน เช่น โมดูลควบคุมอัตโนมัติ โมดูลควบคุมด้วยผู้ใช้งาน และโมดูลแสดงผล เพื่อให้สะดวกต่อการแก้ไข ปรับปรุง และพัฒนาต่อยอดในอนาคต

โค้ดโปรแกรมทั้งหมดถูกจัดเก็บและบริหารจัดการผ่านระบบควบคุมเวอร์ชัน Git โดยรายละเอียดซอร์สโค้ดทั้งหมดจะแสดงไว้ในภาคผนวกของรายงาน

## 4.6 สรุปการทำงานของระบบ

จากการพัฒนาระบบซอฟต์แวร์ดังกล่าว รถต้นแบบสามารถทำงานได้ทั้งในโหมดควบคุมด้วยมนุษย์และโหมดอัตโนมัติ โดยระบบสามารถตรวจจับเป้าหมายด้านหน้า ปรับทิศทางการเลี้ยว และควบคุมการเคลื่อนที่ได้ตามเงื่อนไขที่กำหนดไว้ นอกจากนี้ ระบบยังสามารถนำไปปรับปรุงและพัฒนาต่อยอดเพื่อเพิ่มความสามารถอื่น ๆ ได้ในอนาคต

บทที่ 5

## สรุปผลการดำเนินงานและข้อเสนอแนะ

### 5.1 สรุปผลการดำเนินงาน

จากการดำเนินโครงงานการพัฒนาหุ่นยนต์อัตโนมัติ (Autonomous Robotics Project) กลุ่มผู้จัดทำได้ประสบความสำเร็จในการสร้างรถต้นแบบที่มีการบูรณาการระบบทางกลและซอฟต์แวร์ควบคุมเข้าด้วยกัน โดยสรุปผลการดำเนินงานตามวัตถุประสงค์ได้ดังนี้:

1. การออกแบบและสร้างโครงสร้าง: สามารถออกแบบบอดี้และชิ้นส่วนด้วยโปรแกรม SolidWorks และ Fusion 360 และผลิตออกมาเป็นชิ้นงานจริงที่รองรับความเร็วสูงและมีความเสถียรด้วยระบบโช้คไฮดรอลิก
2. ระบบควบคุมอัตโนมัติ: ระบบสามารถประมวลผลข้อมูลจาก LiDAR และ Gyroscope ผ่าน ROS 2 และ Micro-ROS บน ESP32 เพื่อควบคุมทิศทางด้วยอัลกอริทึม PD Controller ได้อย่างแม่นยำ
3. ระบบการตัดสินใจ: หุ่นยนต์สามารถสลับโหมดการทำงานระหว่างการติดตามรถคันหน้าและการแซงอัตโนมัติเมื่อตรวจพบสิ่งกีดขวางตามเงื่อนไขที่กำหนดไว้ในซอฟต์แวร์
4. ส่วนติดต่อผู้ใช้งาน: พัฒนา GUI ด้วย Tkinter ที่ช่วยให้ผู้ควบคุมสามารถติดตามค่า Telemetry และปรับเปลี่ยนโหมดการทำงาน (Manual/Auto) ได้แบบเรียลไทม์

### 5.2 ปัญหาและอุปสรรคที่พบ

ในระหว่างการดำเนินงาน กลุ่มผู้จัดทำได้พบปัญหาสำคัญและได้ดำเนินการแก้ไขดังนี้:

- ปัญหาด้าน Latency: ในช่วงแรกการรับส่งข้อมูลผ่าน Micro-ROS มีความถี่ต่ำ (1 Hz) ซึ่งได้รับการแก้ไขโดยการปรับปรุงเวอร์ชันของบอร์ดและสภาพแวดล้อม Python ทำให้ระบบตอบสนองได้เร็วขึ้น
- สัญญาณรบกวนและความไม่เสถียร: เซนเซอร์และเซอร์โวมอเตอร์มีอาการส่าย (Oscillation) ซึ่งแก้ไขได้ด้วยการเพิ่ม Alpha Filter เพื่อกรองสัญญาณ และการออกแบบ Node ใน ROS 2 ให้เป็นการประมวลผลแบบรวมศูนย์ (Centralized Processing)
- ข้อจำกัดของฮาร์ดแวร์: ไมโครคอนโทรลเลอร์บางรุ่นมีสมรรถนะไม่เพียงพอต่อการรัน Micro-ROS เต็มรูปแบบ และเซนเซอร์วัดระยะแบบเดิมไม่สามารถตรวจจับได้ตามระยะที่ต้องการ จึงได้เปลี่ยนมาใช้ LiDAR แทน

### 5.3 ข้อเสนอแนะและแนวทางการพัฒนาต่อยอด

เพื่อให้หุ่นยนต์มีประสิทธิภาพสูงขึ้นในอนาคต กลุ่มผู้จัดทำมีข้อเสนอแนะดังนี้:

1. การปรับปรุงระบบประมวลผล: อาจเปลี่ยนไปใช้บอร์ดที่มีประสิทธิภาพสูงขึ้น เช่น NVIDIA Jetson Nano เพื่อรองรับการประมวลผลด้าน Computer Vision และ AI ที่ซับซ้อนขึ้น
2. การพัฒนาอัลกอริทึม: เพิ่มการใช้ Machine Learning ในการคาดการณ์พฤติกรรมของรถคันหน้า (Prediction) แทนการใช้เงื่อนไขแบบ Static เพื่อให้การแซงมีความปลอดภัยมากขึ้นในสภาพการจราจรที่เปลี่ยนไป
3. ระบบพลังงาน: ควรมีการพัฒนาระบบจัดการพลังงาน (Battery Management System) ให้สามารถตรวจสอบสถานะแบตเตอรี่ผ่าน GUI ได้โดยตรง เพื่อป้องกันความเสียหายของแบตเตอรี่ LiPo ขณะใช้งาน

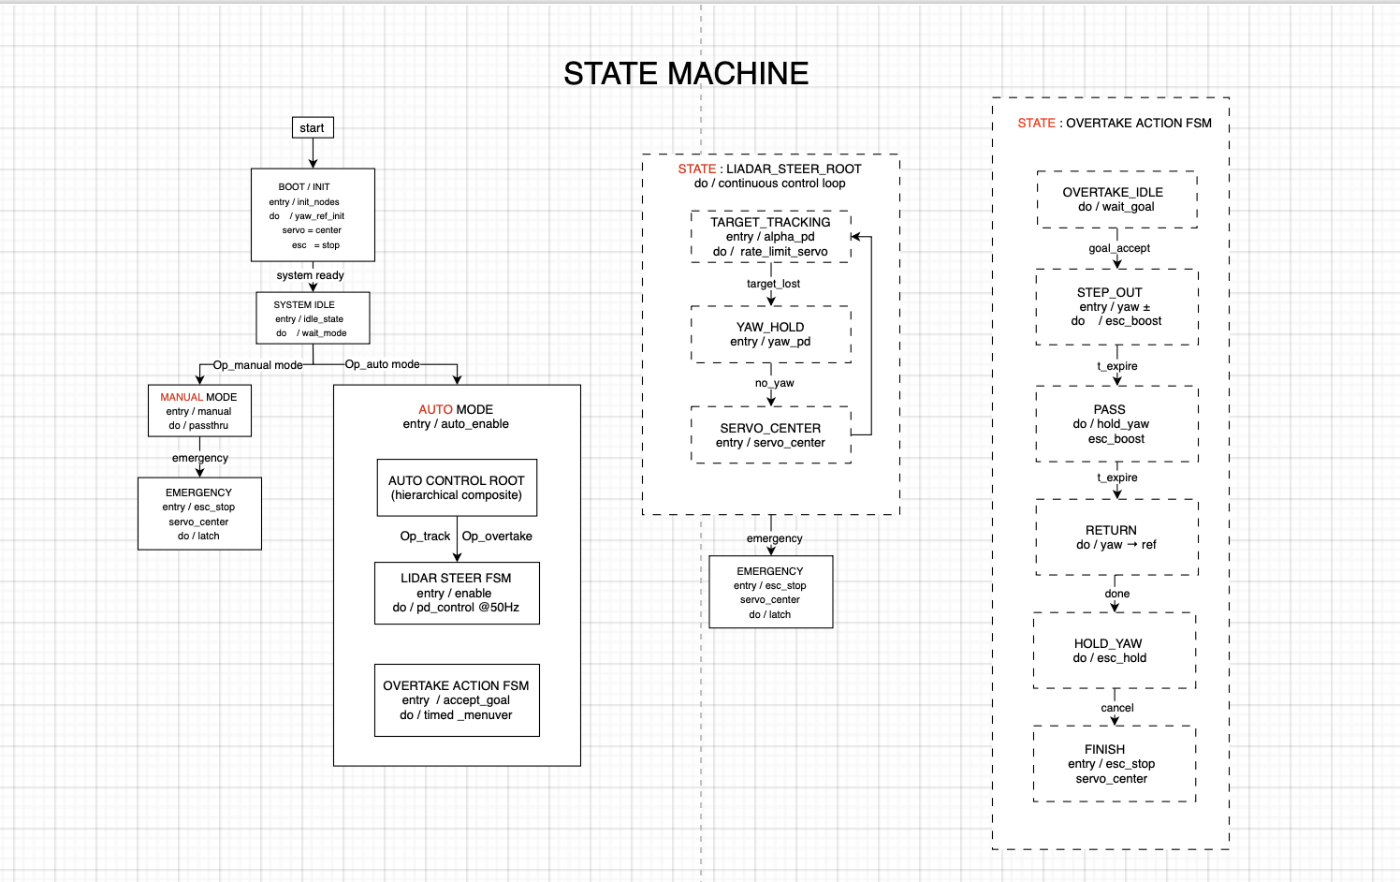
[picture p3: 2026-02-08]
docs/block_diagram.png

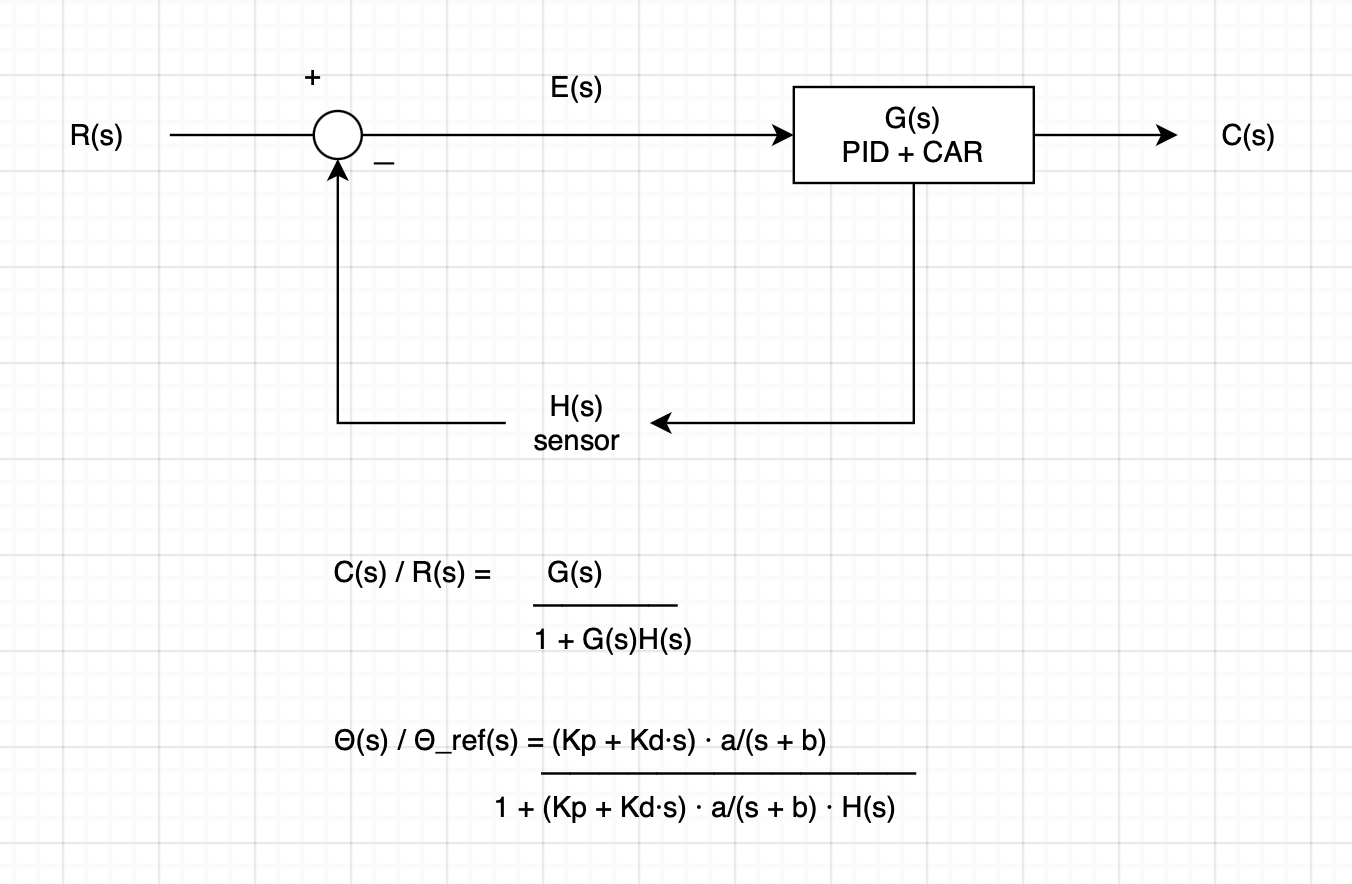
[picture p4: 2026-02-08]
docs/PID.png

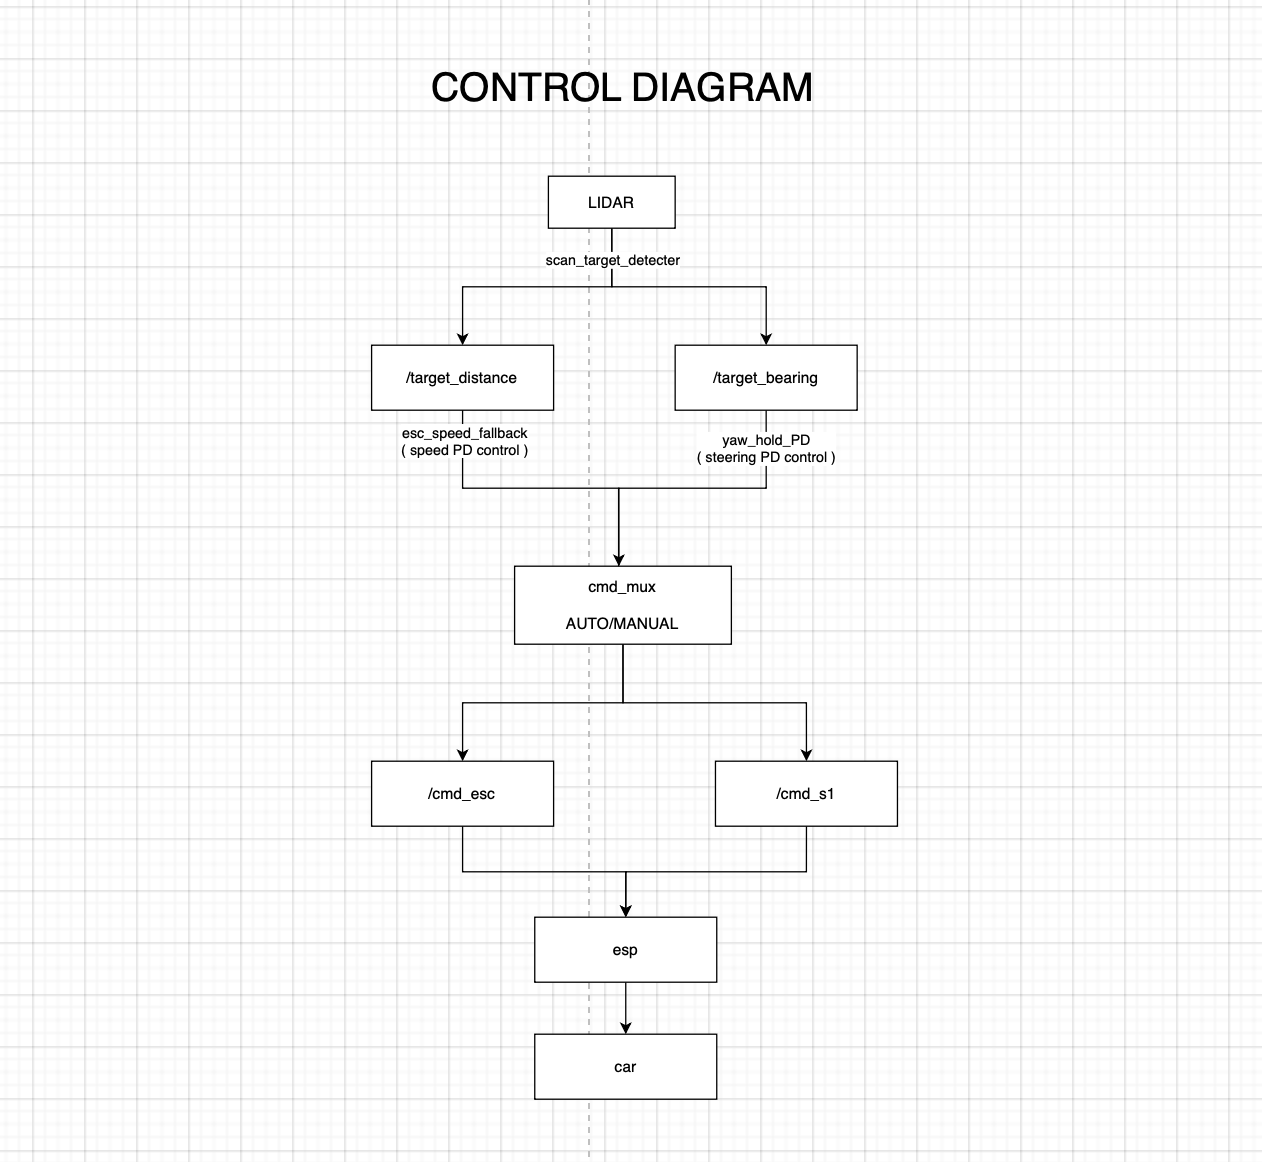
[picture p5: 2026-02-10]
docs/control_diagram.png

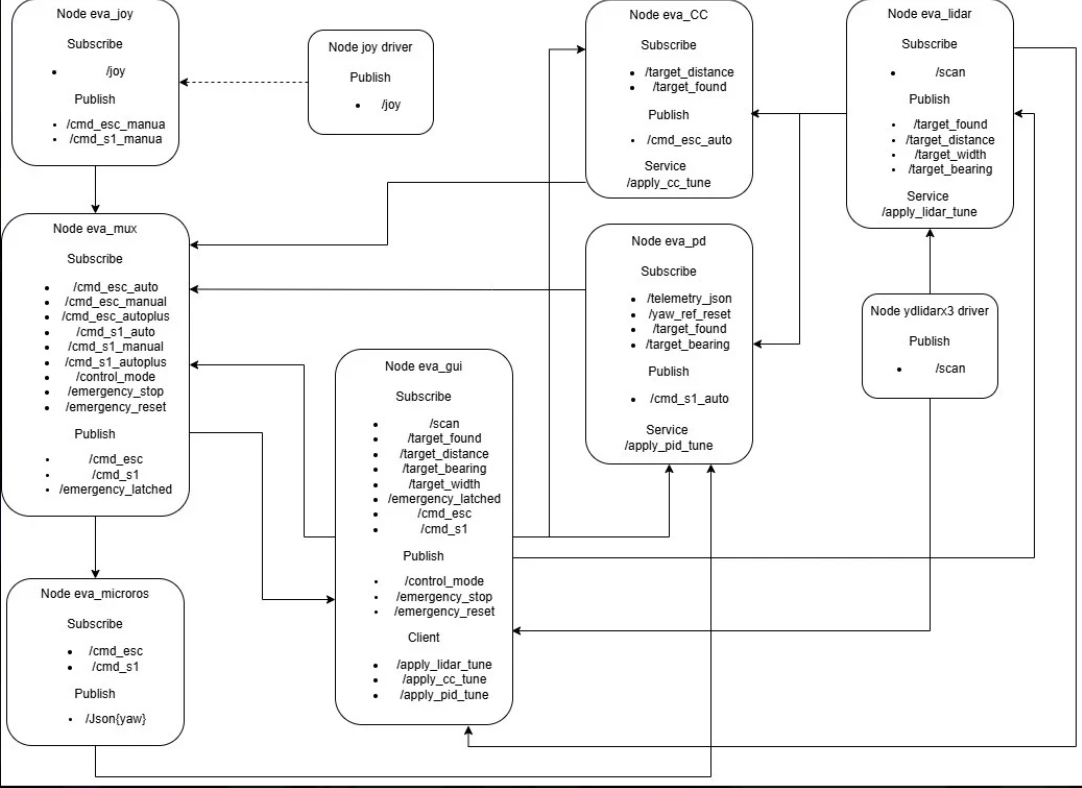
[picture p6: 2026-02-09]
images/block_diagram.png

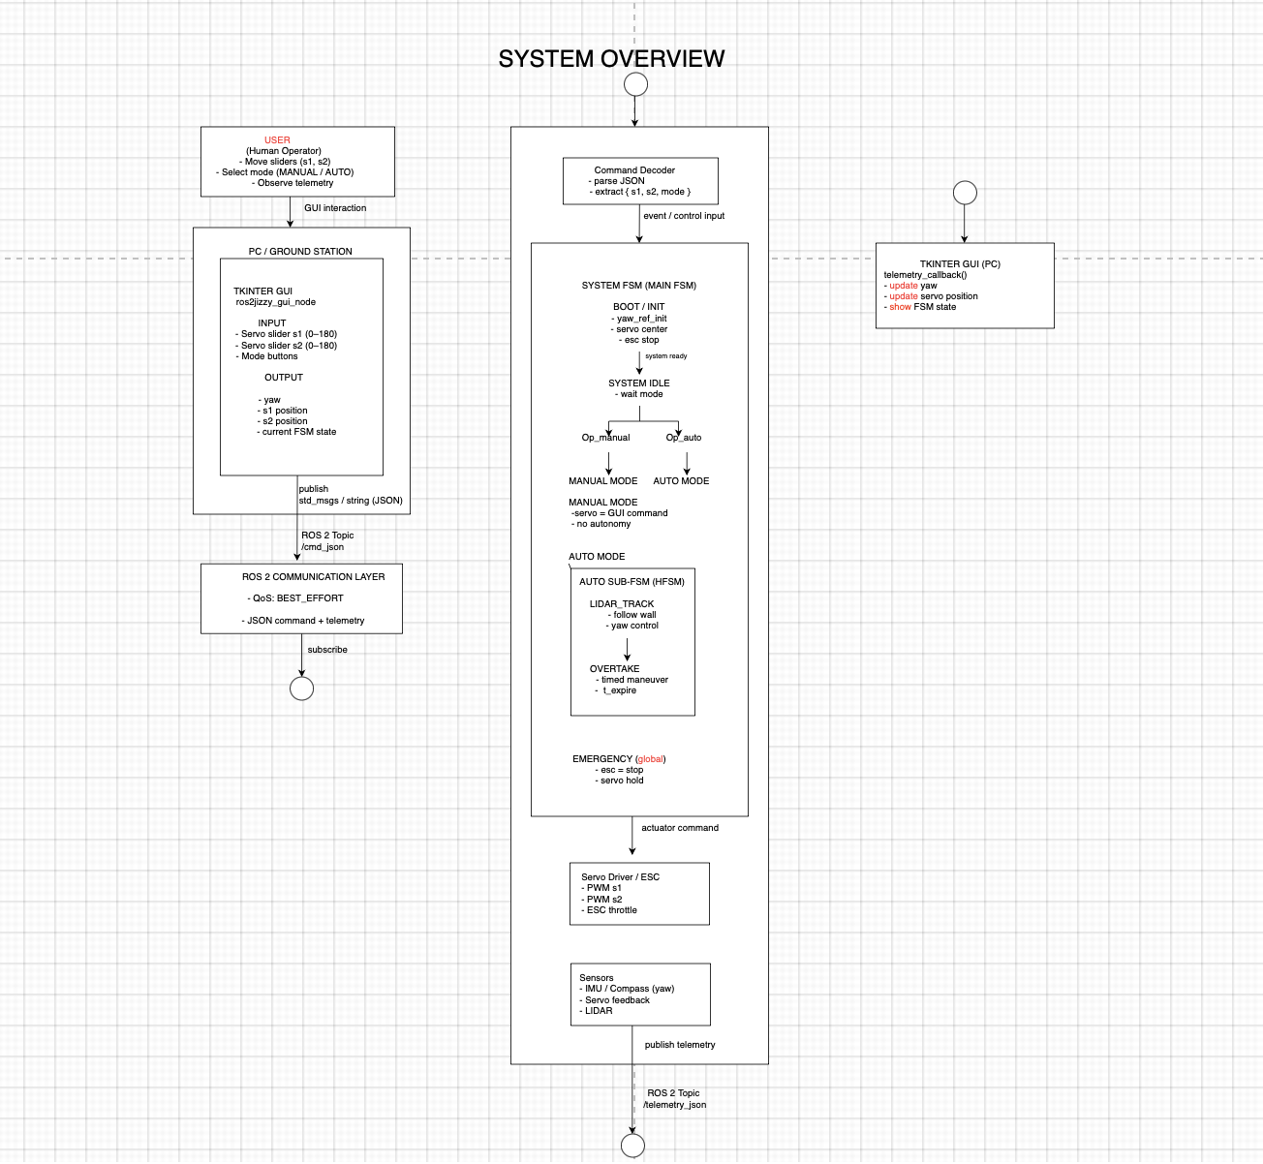
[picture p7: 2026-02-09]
docs/algorithm_flowchart.png

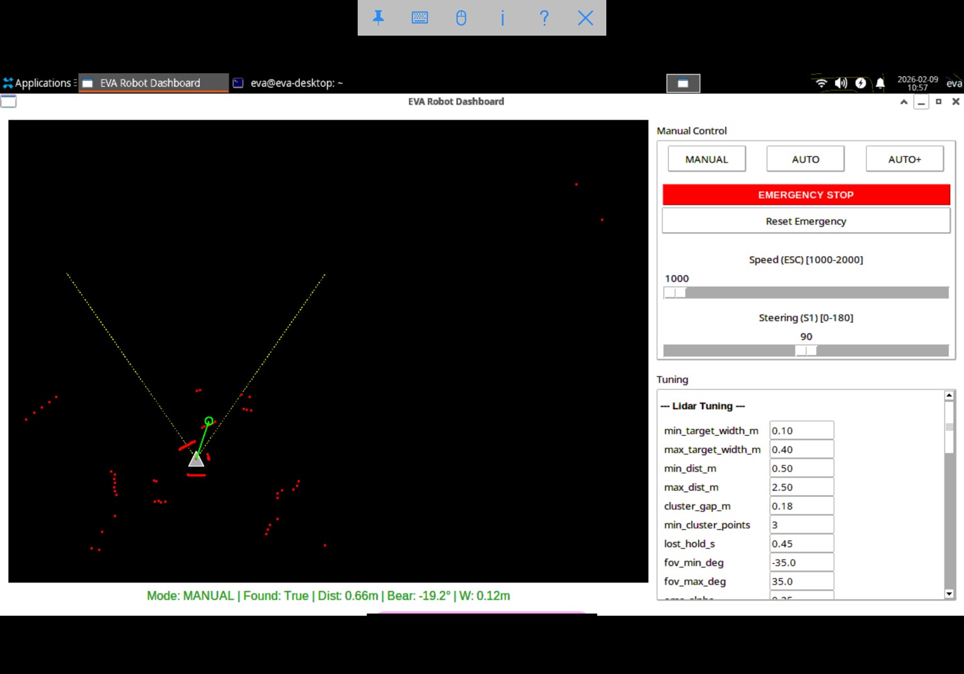
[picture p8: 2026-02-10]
images/GUI.png

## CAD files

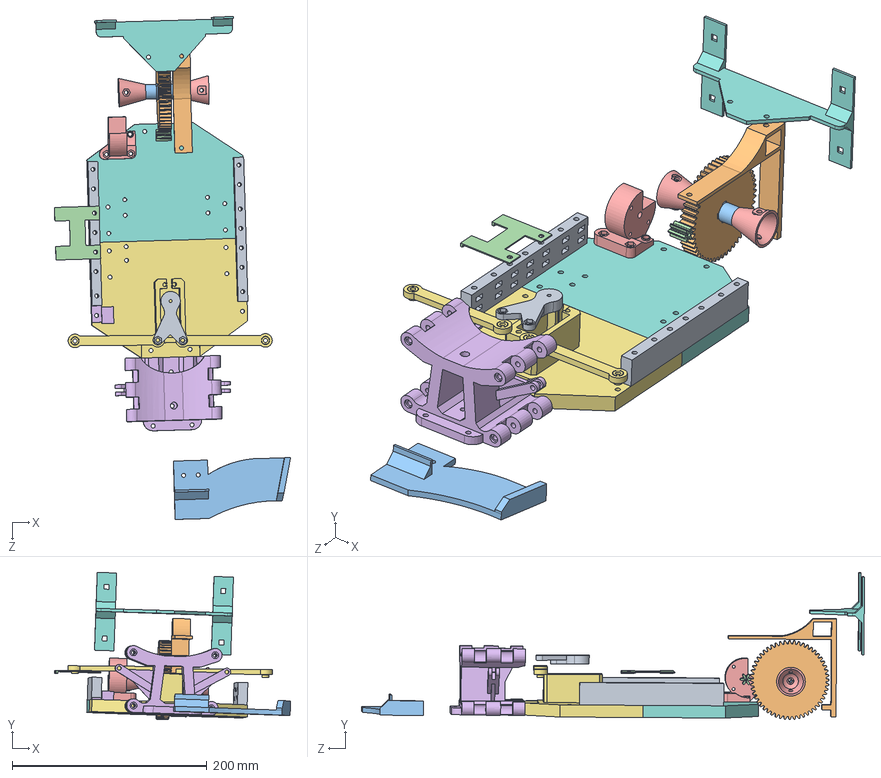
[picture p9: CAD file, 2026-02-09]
models/meshes/Assem2.SLDASM
242.5 x 151.2 x 516.4 mm
BB_Base
FF_Base
FFDrive_BaseV2
Body_sideL x 2
MoterV3
Battery_Lid
F1_2
SpoilerTouch2
Spur Gear (52 teeth).step
Driven_axel
Spur Gear (6 teeth).step
CoverJoint_in x 2
Servohorn
Gyro
ServoarmV85 x 2
Futureboard

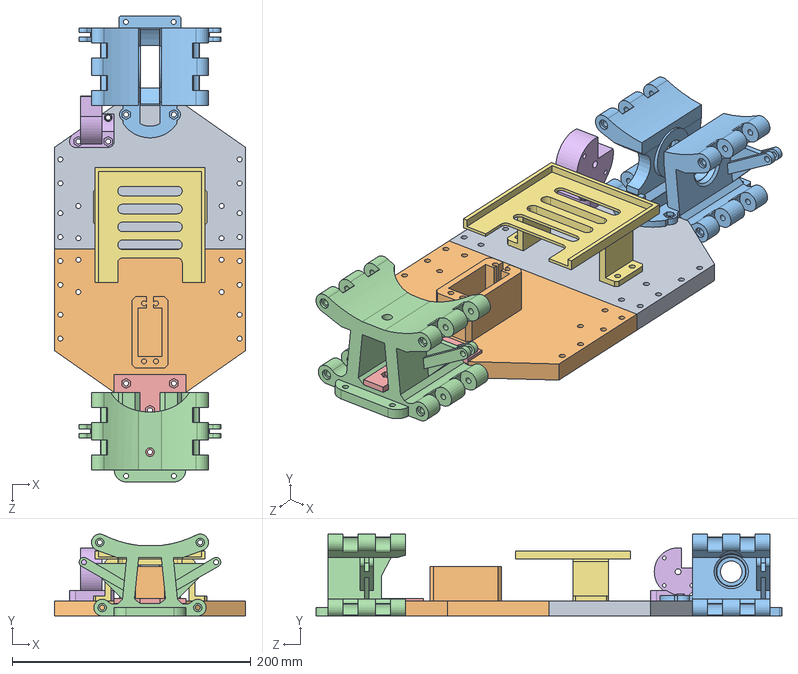
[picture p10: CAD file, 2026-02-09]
models/meshes/Assem3.SLDASM
160.0 x 68.6 x 390.0 mm
BB_Base
FF_Base
BBDrive_BaseV82
FFDrive_BaseV2
FFBody_to_Drive
MoterV3
Pi5_coverB

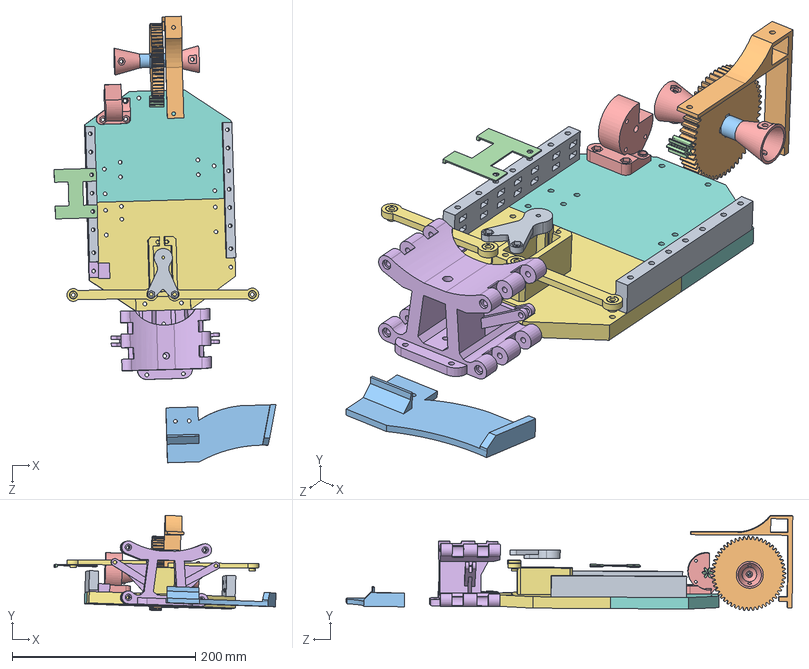
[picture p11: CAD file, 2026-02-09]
models/meshes/Assem1.SLDASM
242.5 x 104.0 x 487.8 mm
BB_Base
FF_Base
FFDrive_BaseV2
Body_sideL x 2
MoterV3
Battery_Lid
F1_2
SpoilerTouch2
Spur Gear (52 teeth).step
Driven_axel
Spur Gear (6 teeth).step
CoverJoint_in x 2
Servohorn
Gyro
ServoarmV85 x 2

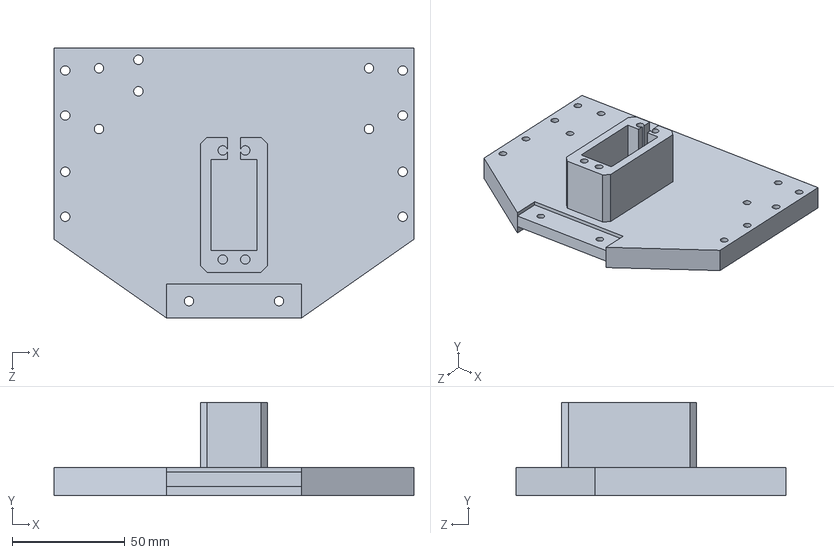
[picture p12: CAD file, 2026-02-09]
models/cad/FF_Base.SLDPRT
160.0 x 41.5 x 120.0 mm

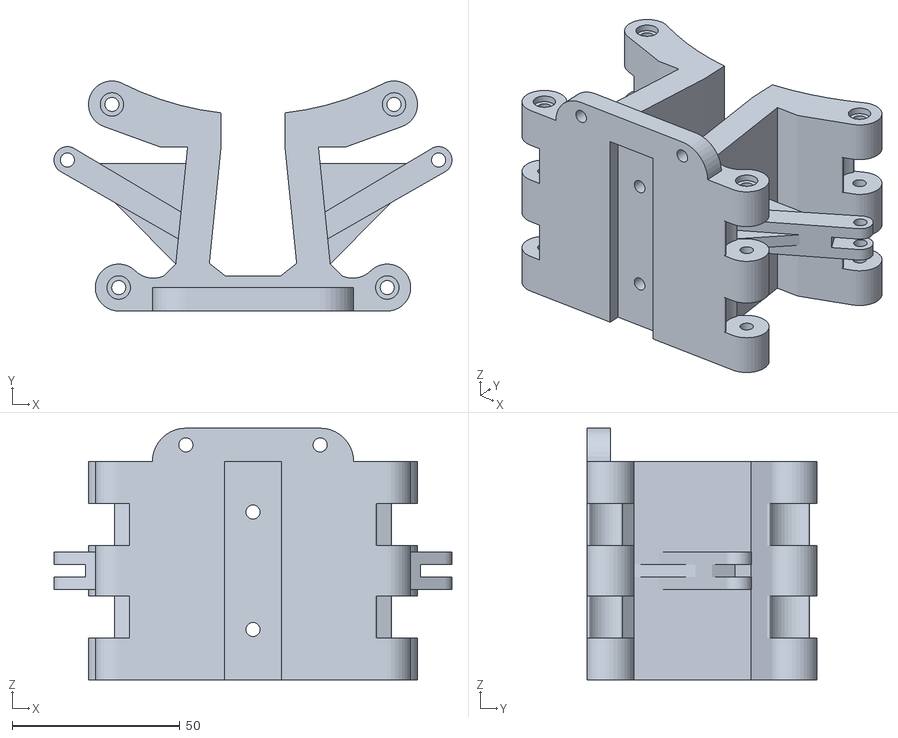
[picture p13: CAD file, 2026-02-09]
models/cad_stl/FFDrive_Base.STL
118.6 x 68.6 x 75.0

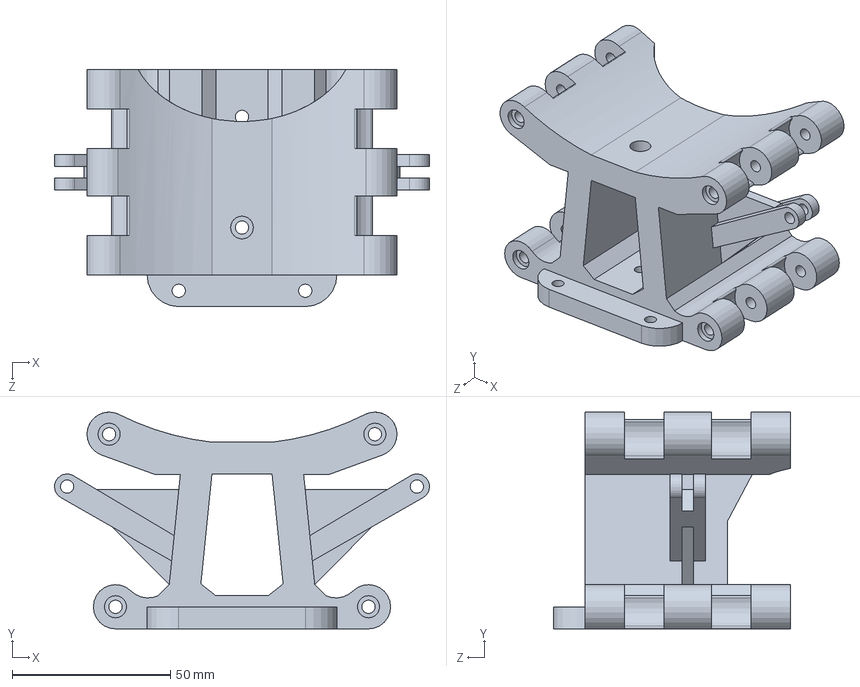
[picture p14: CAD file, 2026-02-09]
models/cad/FFDrive_BaseV2.SLDPRT
118.6 x 68.6 x 75.0 mm

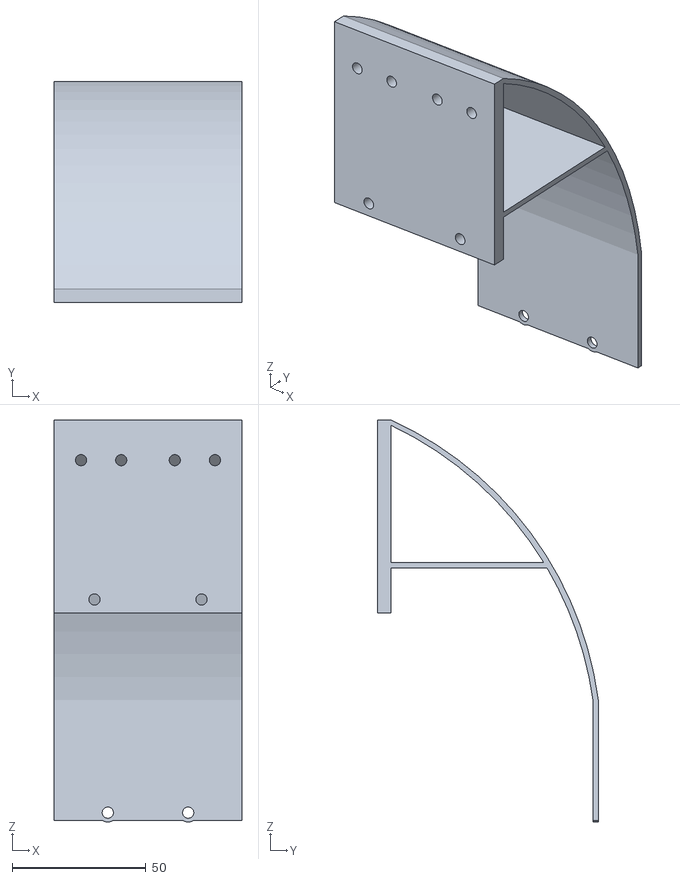
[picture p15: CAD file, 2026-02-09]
models/cad_stl/F1_1.STL
70.0 x 82.4 x 150.1

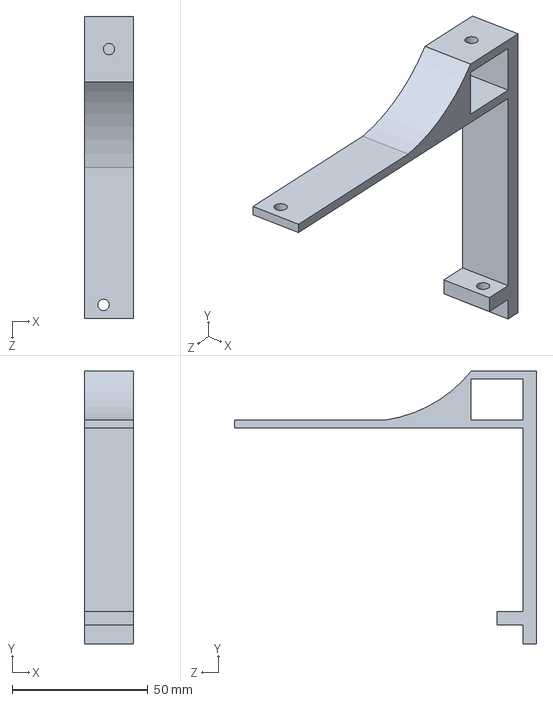
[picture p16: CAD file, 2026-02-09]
models/cad/SpoilerTouch2.SLDPRT
18.0 x 100.4 x 111.1 mm

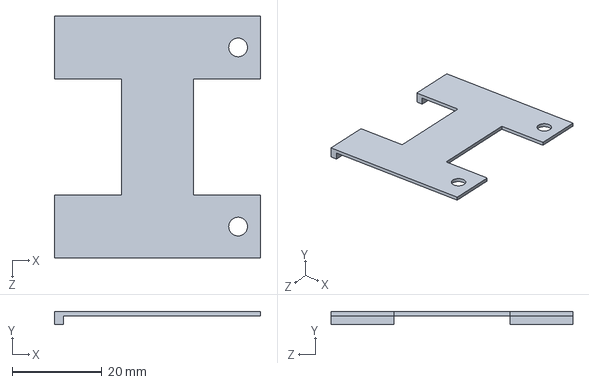
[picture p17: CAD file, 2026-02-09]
models/cad/Battery_Lid.SLDPRT
46.0 x 3.00 x 54.0 mm

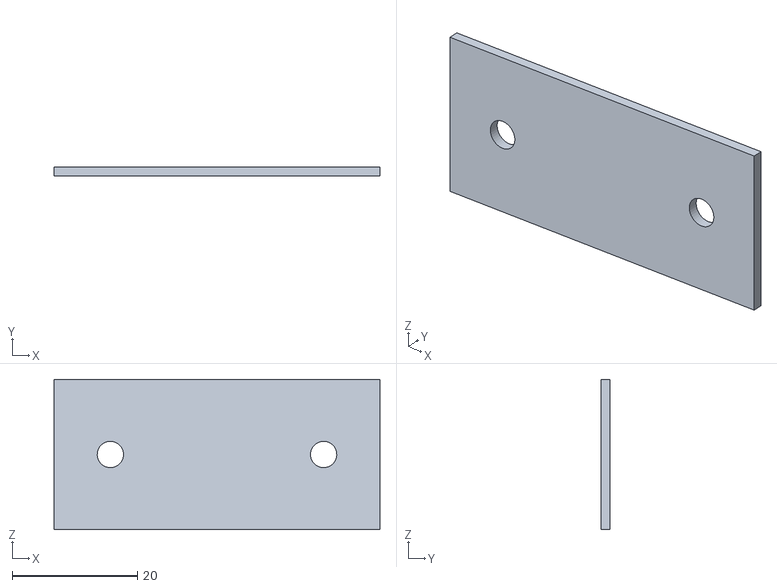
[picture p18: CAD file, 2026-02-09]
models/cad_stl/SpoilerMiddle.STL
52.1 x 1.50 x 24.0

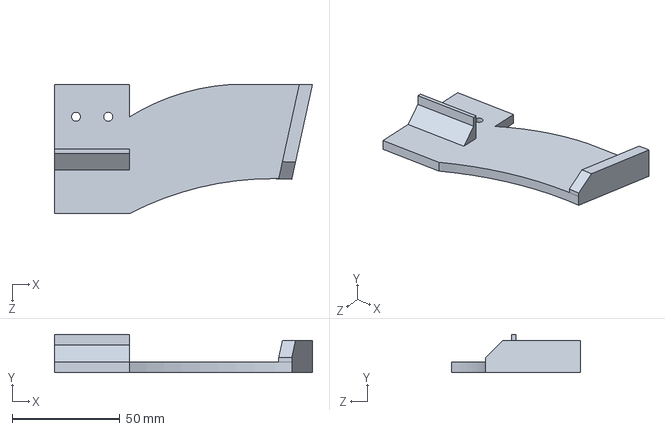
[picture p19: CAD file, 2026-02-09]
models/cad/F1_2.SLDPRT
120.0 x 17.9 x 60.0 mm

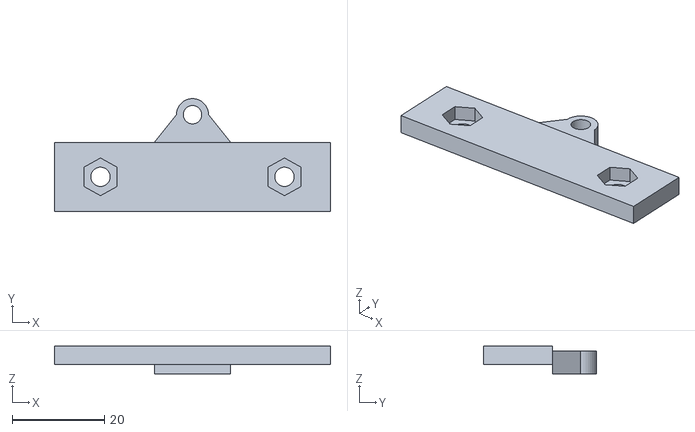
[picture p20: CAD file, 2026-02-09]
models/cad_stl/SeizeFLow.STL
60.0 x 24.5 x 6.00

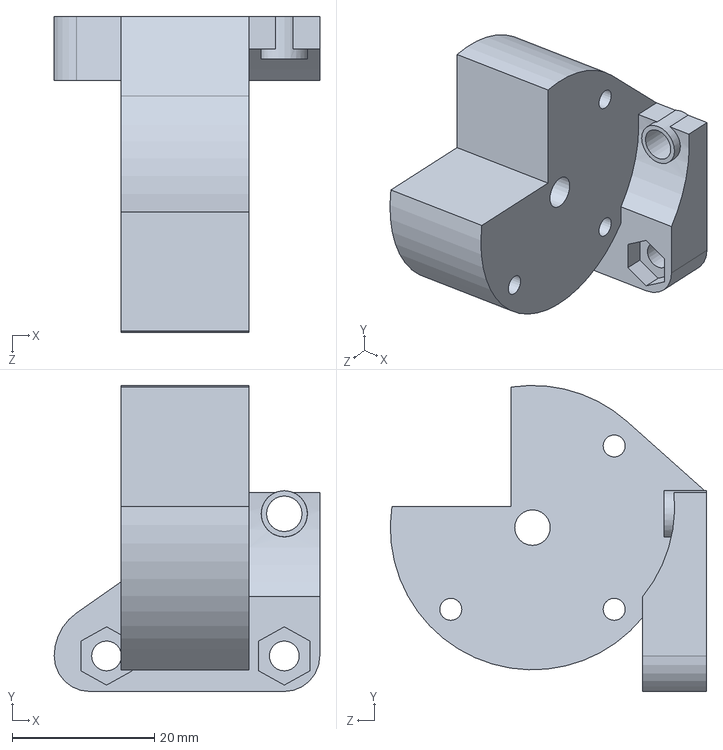
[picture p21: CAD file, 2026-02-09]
models/cad/MoterV3.SLDPRT
37.4 x 43.0 x 44.5 mm

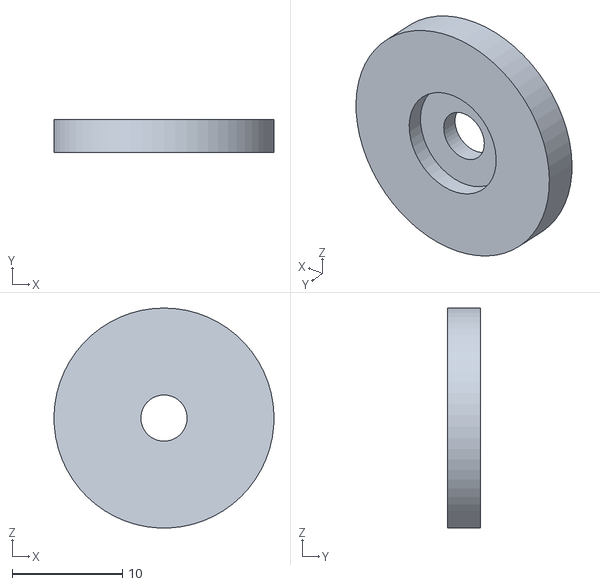
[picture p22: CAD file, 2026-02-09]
models/cad_stl/LockSharp.STL
20.0 x 3.00 x 20.0

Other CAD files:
models/cad/BB_Base.SLDPRT
models/cad_stl/GearRccar46T.stl
models/cad/Servohorn.SLDPRT
models/cad_stl/axle.stl
models/cad/BBDrive_Base.SLDPRT
models/cad/BBDrive_BaseV82.SLDPRT
models/cad/Battery.SLDPRT
models/cad/BatteryV2.SLDPRT
models/cad/Body_sideL.SLDPRT
models/cad/Box.SLDPRT
models/cad/BoxBigSize.SLDPRT
models/cad/BoxsmallSize.SLDPRT
models/cad/CoverJoint_in.SLDPRT
models/cad/Driven_axel.SLDPRT
models/cad/F1_2_2.SLDPRT
models/cad/FFBody_to_Drive.SLDPRT
models/cad/Futureboard.SLDPRT
models/cad/GearRccar52T.SLDASM
models/cad/GearRccar52T.step
models/cad/GearRccar6T.SLDASM
models/cad/GearRccar6T.step
models/cad/Gyro.SLDPRT
models/cad/Lidar.SLDPRT
models/cad/LidarArmBack.SLDPRT
models/cad/LidarArmL.SLDPRT
models/cad/LidarArmMiddle.SLDPRT
models/cad/LidarArmR.SLDPRT
models/cad/Pi5_coverB.SLDPRT
models/cad/Pi5_coverF.SLDPRT
models/cad/Radio.SLDPRT
models/cad/SeizeF.SLDPRT
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

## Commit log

2026-02-08 add PID Diagram
2026-02-09 update algorithm flowchart image
2026-02-09 add ESC PD fallback controller node
2026-02-09 add LiDAR target detection and tracking node
2026-02-09 add yaw hold PD steering controller
2026-02-09 add system images (block diagram, hardware, PID)
2026-02-09 add CAD model image
